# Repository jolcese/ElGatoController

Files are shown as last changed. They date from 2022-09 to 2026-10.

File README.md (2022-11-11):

# EL Gato Controller
  

  ## Description
  This is a standalone controller for the ElGato Lights. It's based on an ESP-WROOM-32 module but any ESP32 (or even ESP8266) should work with minimal changes.

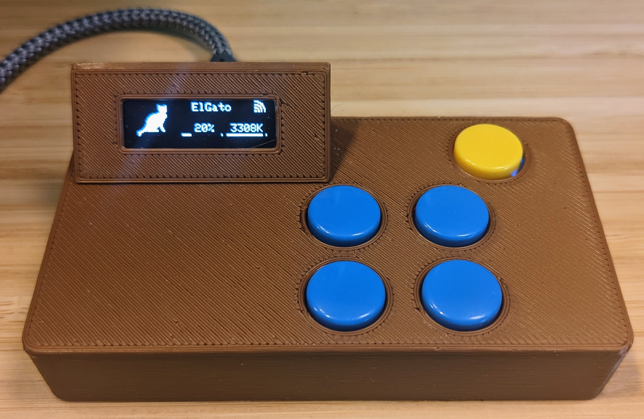
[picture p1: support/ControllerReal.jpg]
  <figure><figcaption>Controller with Display and 3D Printed Case</figcaption></figure>
  <br>
  <br>
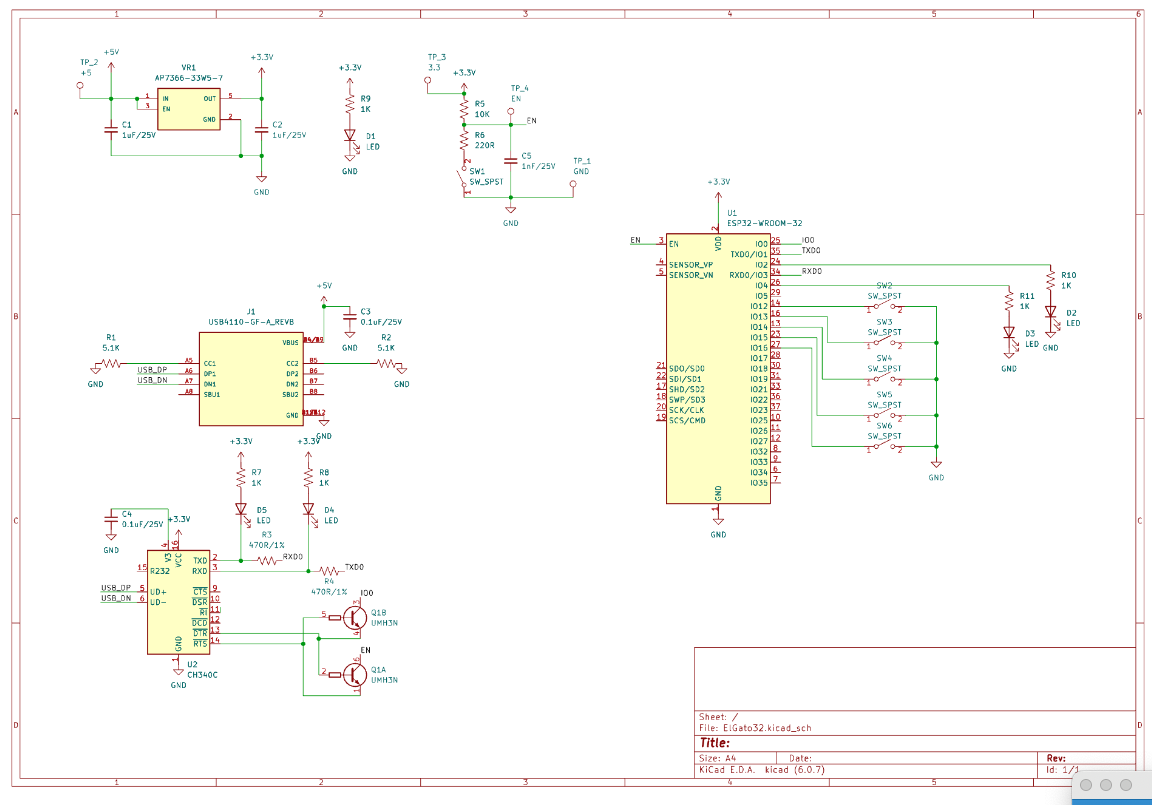
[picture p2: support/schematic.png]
  <figure><figcaption>Schematic for the module, USB-UART controller and buttons</figcaption></figure>
  <br>
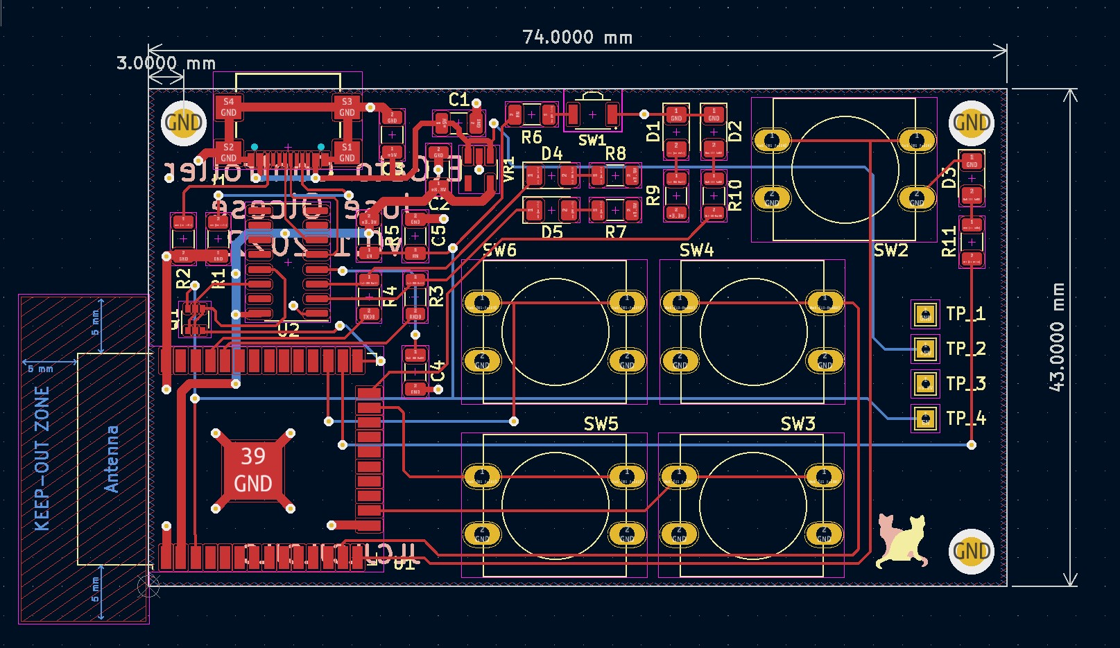
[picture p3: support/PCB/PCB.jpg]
  <figure><figcaption>Display has been added after designing the PCB so no header/connector</figcaption></figure>
  <br>

  ## Table of Contents
  * [ToDo](#todo)
  * [Installation](#installation)
  * [Usage](#usage)
  * [License](#license)
  * [Contributing](#contributing)
  * [Tests](#tests)
  * [Questions](#questions)

  ## ToDo
  
  - NTP
  - Dynamic lights config/ Web Server
  - Shortcut reboot
  - Brightness
  - Faster REST
  - FIx BAR size
  - ~Wifi Portal~
  - ~OLED Status~
  ## Installation
  Some of the tools used to build this project
  - [Plaftormio](https://platformio.org/)
  - [Kicad](https://www.kicad.org/)
  ## Usage
  Currently, the IPs for both lights are hardcoded. Until I made that discoverable thru Bonjour, numbers of lights and IPs will need to be manually mofified.
  
    main.cpp
    
    const String sLight1 = "192.168.30.137";
    const String sLight2 = "192.168.30.161";

  ## License
  This project is license under MIT

  ## Contributing
  Nothing

  ## Tests
  no tests

  ## Questions
  If you have any questions about this projects, please contact me directly at jolcese@gmail.com. You can view more of my projects at https://github.com/jolcese.

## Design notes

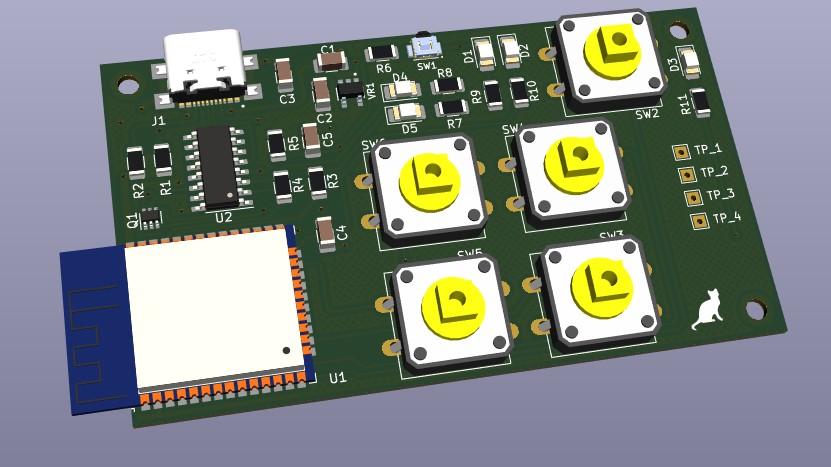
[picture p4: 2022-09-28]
support/3DModel-4.jpg

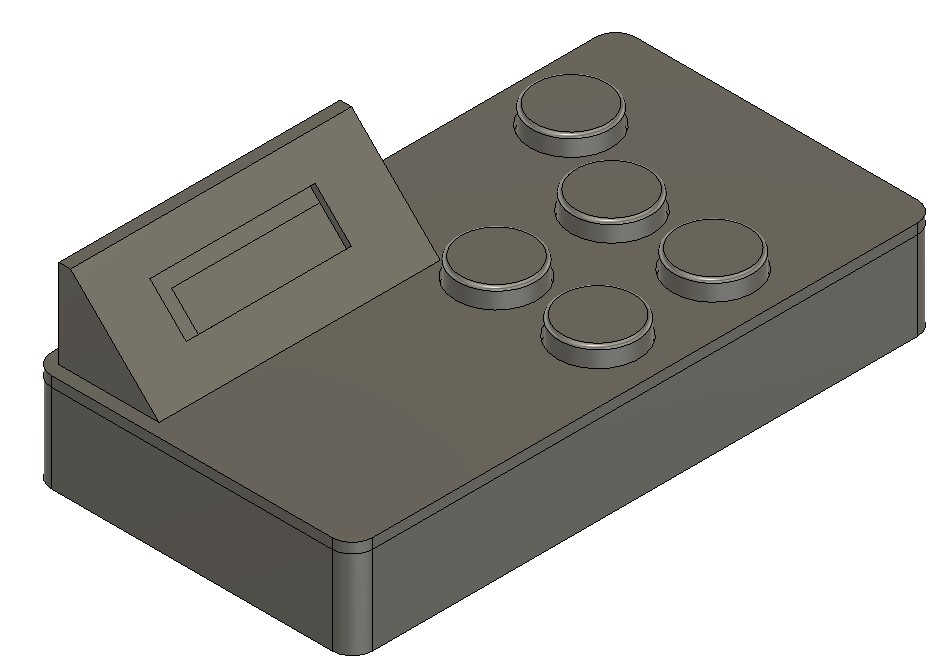
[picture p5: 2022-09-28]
support/3DModel-3.jpg

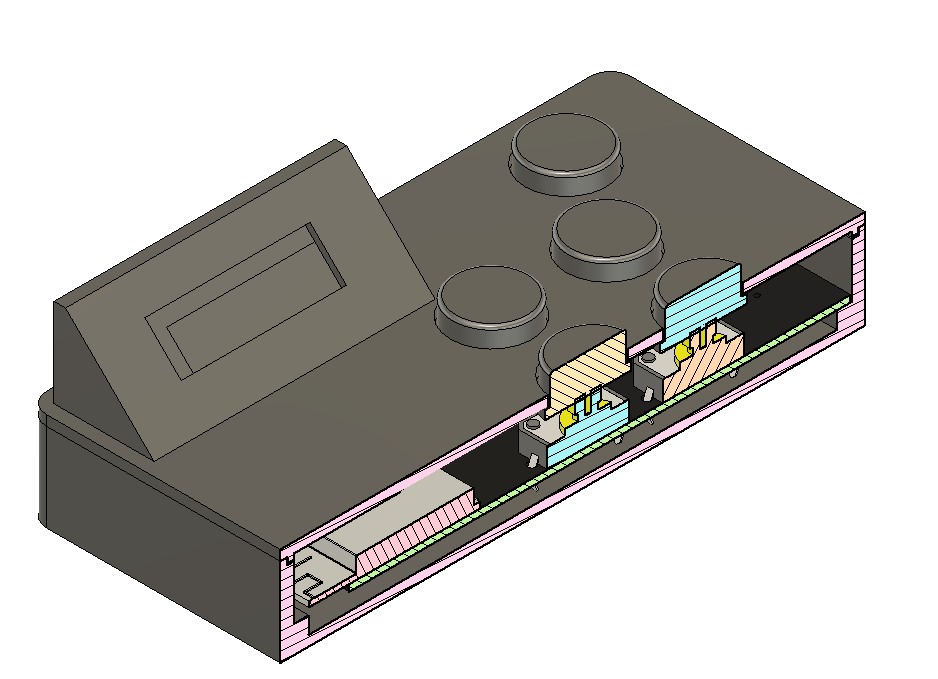
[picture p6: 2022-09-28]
support/3DModel-2.jpg

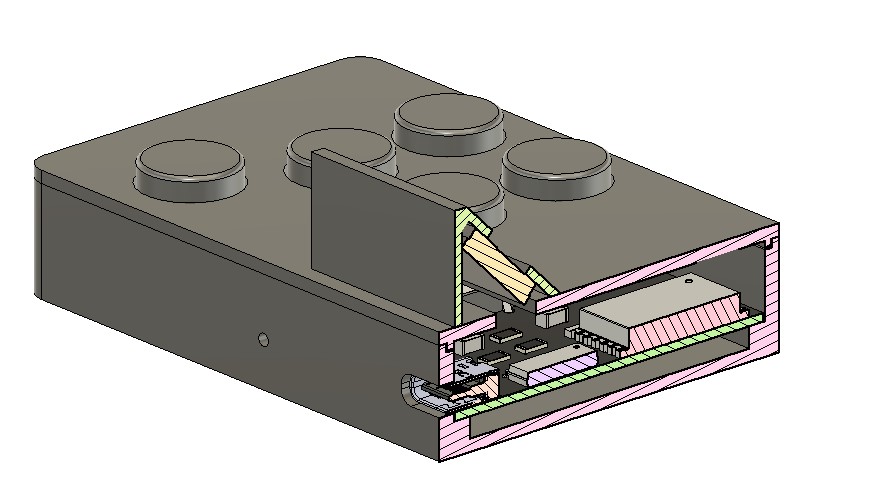
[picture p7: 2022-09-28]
support/3DModel-1.jpg

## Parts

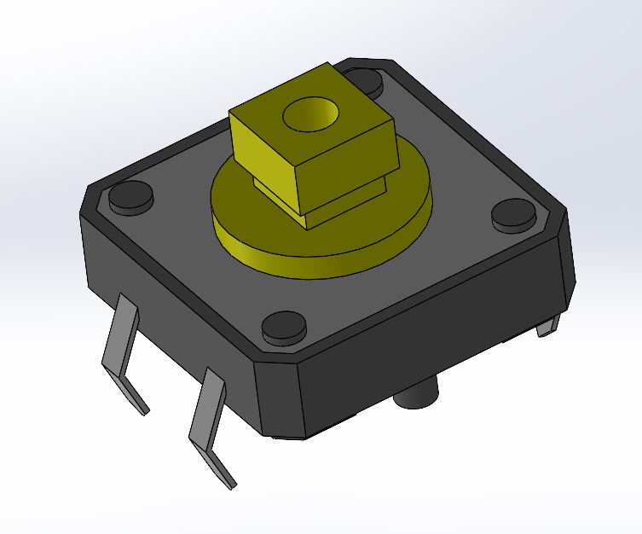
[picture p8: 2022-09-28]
kicad/ElGato32/Components/omron-b3f-12mm-tact-switch-1.snapshot.1/omron B3F/OMRON B3F 12mm TACT SWITCH..JPG

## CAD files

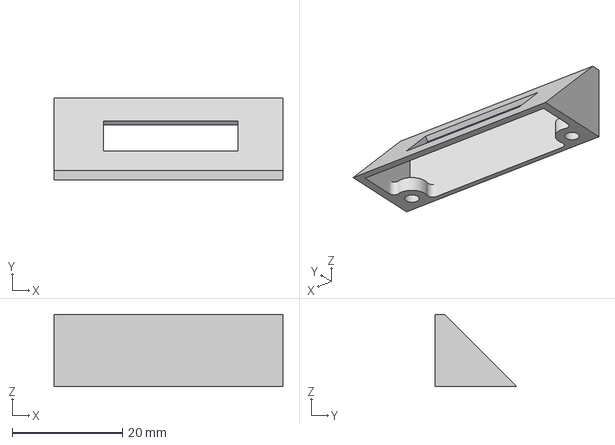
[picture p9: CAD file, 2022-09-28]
enclosure/Display.3mf
41.5 x 14.8 x 13.1 mm

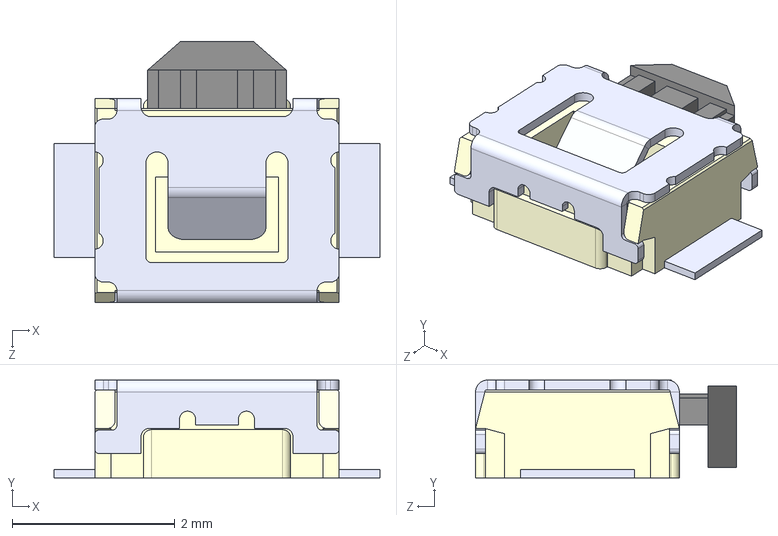
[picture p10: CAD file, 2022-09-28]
kicad/ElGato32/Components/B3U-3000P--3DModel-STEP-56544.STEP
4.00 x 1.20 x 3.20 mm

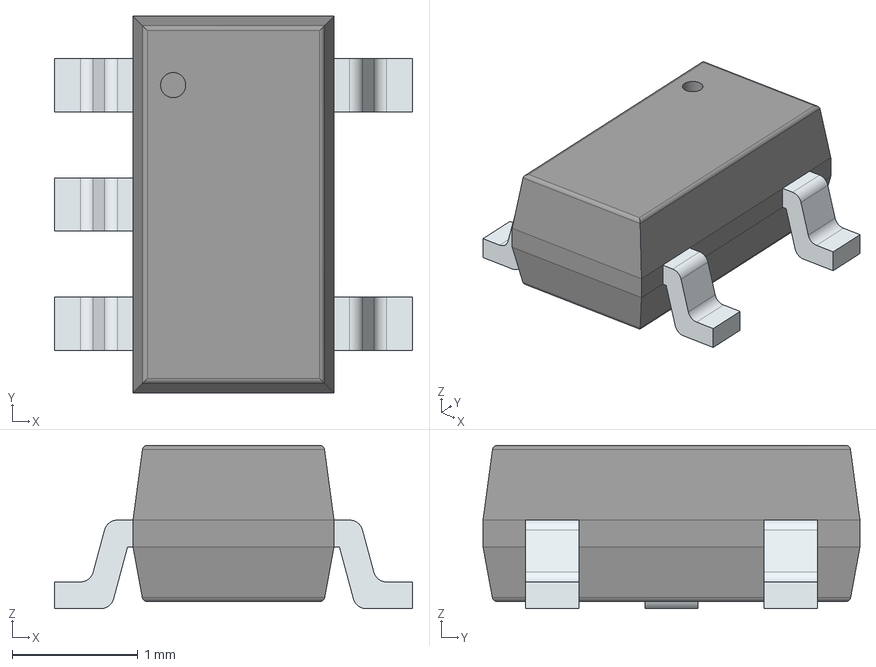
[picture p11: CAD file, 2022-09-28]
kicad/ElGato32/Components/LIB_AP7366-33W5-7/AP7366-33W5-7/3D/AP7366-33W5-7.stp
2.85 x 3.00 x 1.30 mm
PinsArrayL
PinsArrayR

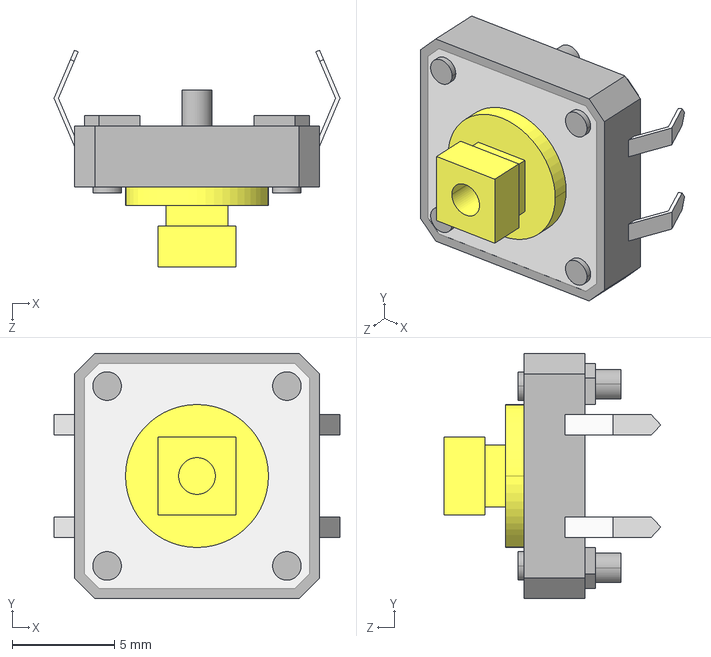
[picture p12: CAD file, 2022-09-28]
kicad/ElGato32/Components/omron-b3f-12mm-tact-switch-1.snapshot.1/omron B3F/OMRON B3F 12mm TACT SWITCH.STEP
14.0 x 12.0 x 10.6 mm

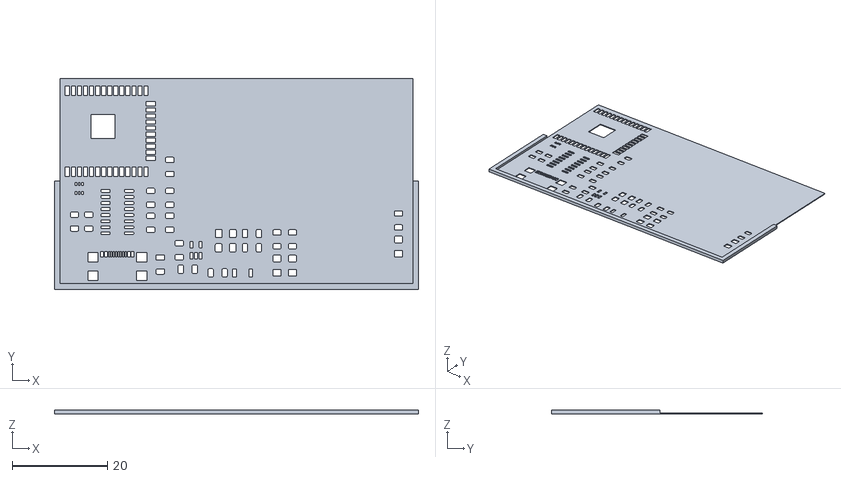
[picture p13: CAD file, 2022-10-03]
support/PCB/SolderPasteStencil-gts-8576637044.stl
76.4 x 44.2 x 0.8

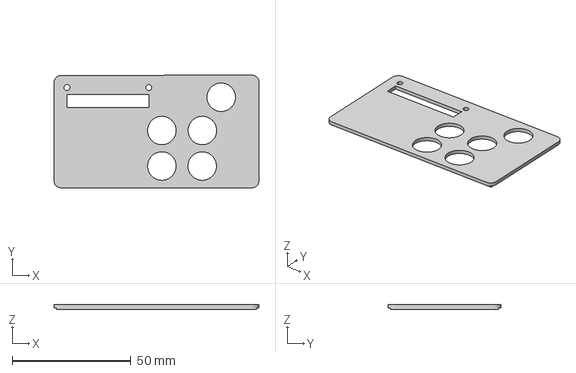
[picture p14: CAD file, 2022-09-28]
enclosure/Lid.3mf
86.4 x 47.5 x 2.30 mm

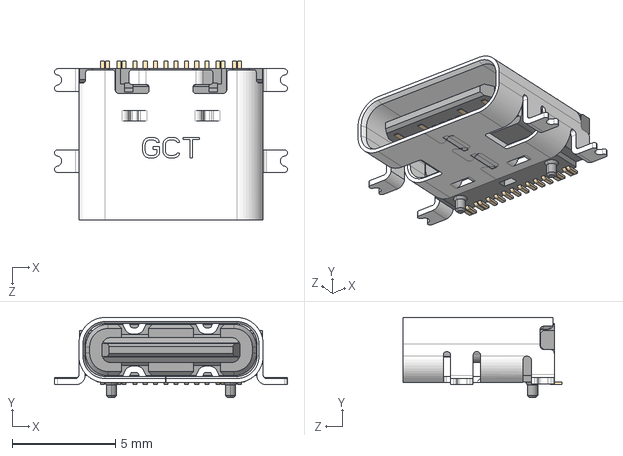
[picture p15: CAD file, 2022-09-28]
kicad/ElGato32/Components/USB4110-GF-A--3DModel-STEP-269445.STEP
11.3 x 3.89 x 7.70 mm

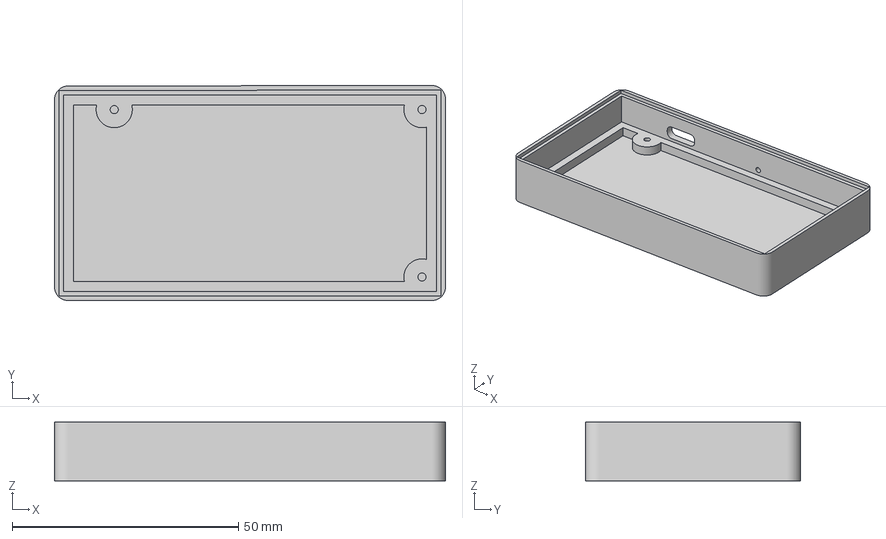
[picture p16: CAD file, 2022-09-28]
enclosure/Base.3mf
86.4 x 47.5 x 13.0 mm

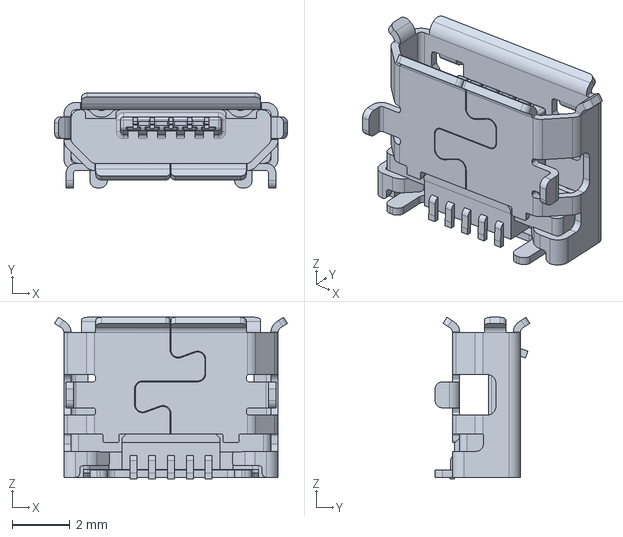
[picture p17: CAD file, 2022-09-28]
kicad/ElGato32/Components/10118194-0001LF/10118194-0001LF.step
8.05 x 3.27 x 5.58 mm

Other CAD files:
kicad/ElGato32/Components/LIB_AP7366-33W5-7/AP7366-33W5-7/Allegro/sot95p285x130-5n.psm
kicad/ElGato32/Components/LIB_AP7366-33W5-7/AP7366-33W5-7/DEHDL/ap7366_33w5_7/chips/chips.prt
kicad/ElGato32/Components/_Wemos.8a6fa8fd-bdae-4608-9551-e9ac450bc9c8.f3d

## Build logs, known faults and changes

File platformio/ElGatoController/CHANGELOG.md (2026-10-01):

# Changelog

All notable changes to the ElGato Controller firmware are documented here.

The format is based on [Keep a Changelog](https://keepachangelog.com/en/1.1.0/),
and this project adheres to [Semantic Versioning](https://semver.org/spec/v2.0.0.html).

The firmware version lives in [`include/version.h`](include/version.h) and is
printed over serial at startup, together with the git commit it was built from.

## [Unreleased]

## [0.6.0] - 2026-10-01

### Changed
- Button presses now update the on-screen state (brightness/temperature/on-off)
  immediately for instant visual feedback, instead of only after the network
  request. The light PUT follows a moment later, batched. Makes rapid repeated
  clicks feel responsive. `actionLight()` now just sends the current state.
- While no lights are known, discovery retries every 30s instead of waiting the
  full 5-minute poll interval, so a transient discovery miss at startup recovers
  quickly.

## [0.5.0] - 2026-10-01

### Changed
- Much faster button-to-light response: the action batching window dropped from
  600 ms to 150 ms, the blocking GET that ran before every action was removed
  (deltas apply to locally tracked state instead), and Nagle buffering is
  disabled on the PUT so the request goes out immediately.

## [0.4.0] - 2026-10-01

### Added
- Periodic mDNS re-discovery (every 30 min) plus automatic re-discovery when a
  known light stops answering, so a light that changed IP (DHCP) self-heals
  without needing to restart the controller or the light.
- Lights connectivity indicator on the display (top-left): a filled dot when the
  lights are reachable, a hollow circle with a slash when they are not.

### Fixed
- Color temperature bar moved opposite to the Kelvin number; the bar now tracks
  the displayed K value (low K = short bar).
- Disabled WiFi modem power save, which was dropping multicast packets and making
  mDNS discovery intermittently find only some (or none) of the lights.

## [0.3.0] - 2026-10-01

### Added
- OLED anti burn-in power management: the display dims after 15s idle and fully
  blanks after 60s idle, waking instantly on any button press. The GDDRAM buffer
  keeps refreshing while blanked, so content is current the moment it wakes.

### Changed
- mDNS discovery now runs multiple query passes and merges unique light IPs,
  instead of trusting a single query. Fixes only some lights being found when
  one doesn't answer the first query.

### Fixed
- Color temperature up/down buttons were inverted; swapped SW4/SW6 so each
  button changes temperature in the expected direction.

## [0.2.0] - 2026-10-01

### Added
- Automatic discovery of Elgato Key Lights over mDNS (`_elg._tcp`), replacing
  the two hardcoded IP addresses. Up to `MAX_LIGHTS` lights are now controlled.
- Firmware version tracking: `FW_VERSION` plus the git commit hash are compiled
  into the firmware and printed on the serial console at boot.

### Changed
- `getLightState()` reads from the first discovered light; `actionLight()` pushes
  updates to every discovered light.
- mDNS discovery retries a few times, since the first query after connecting
  often misses responses.

## [0.1.0] - initial

### Added
- WiFi provisioning via WiFiManager, OLED display, physical buttons for on/off,
  brightness and color temperature, controlling two Elgato lights at hardcoded
  IP addresses.

[Unreleased]: https://github.com/
[0.2.0]: https://github.com/
[0.1.0]: https://github.com/

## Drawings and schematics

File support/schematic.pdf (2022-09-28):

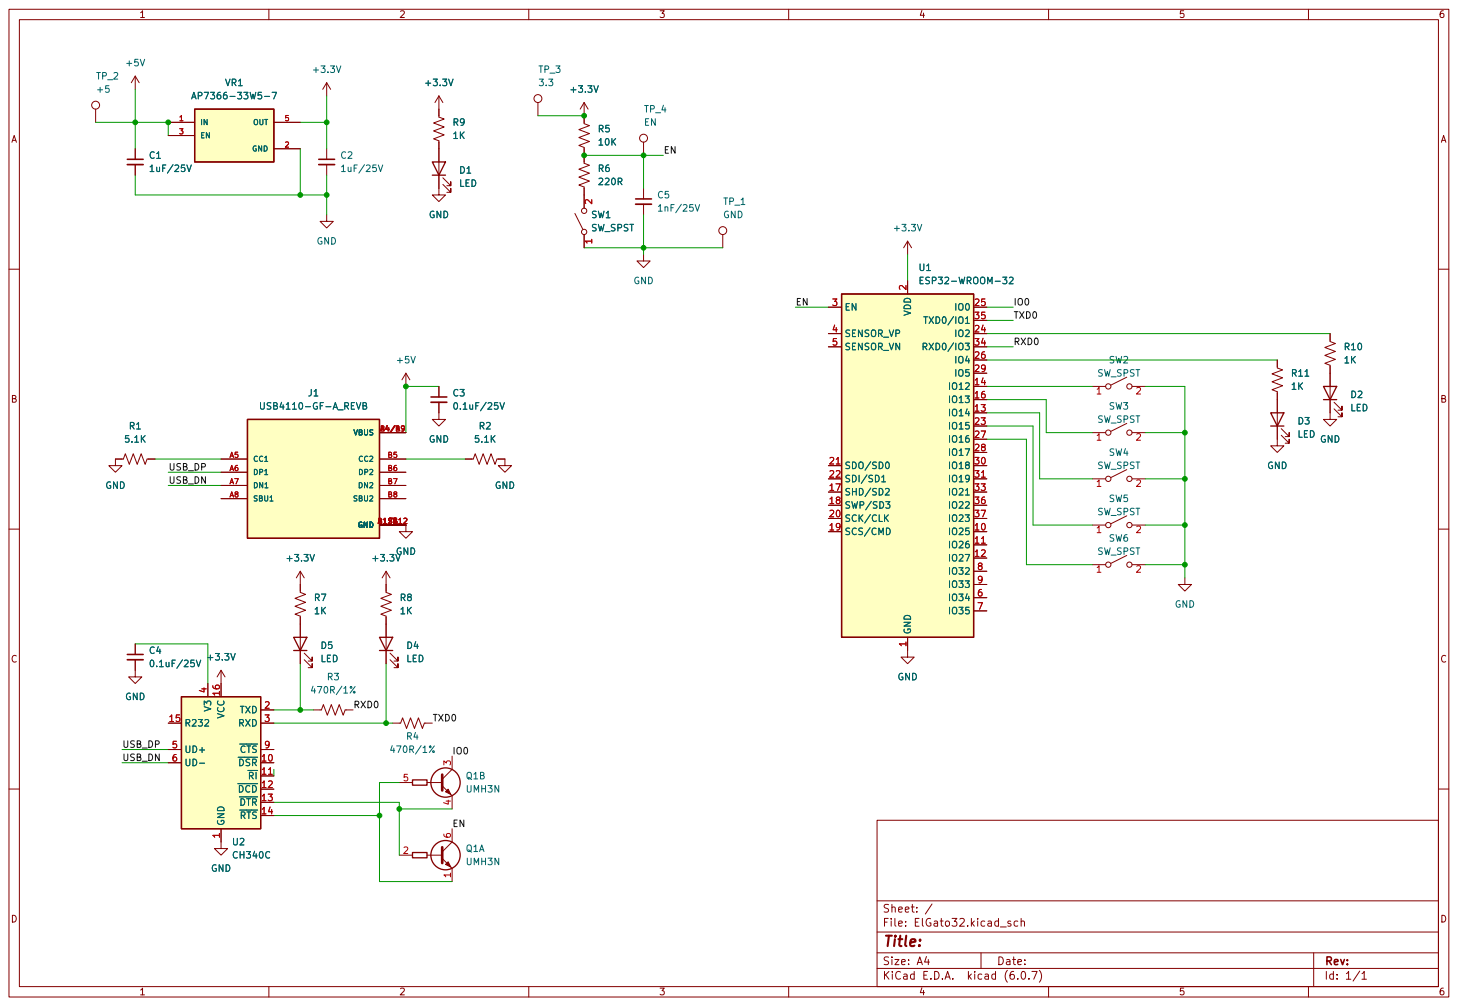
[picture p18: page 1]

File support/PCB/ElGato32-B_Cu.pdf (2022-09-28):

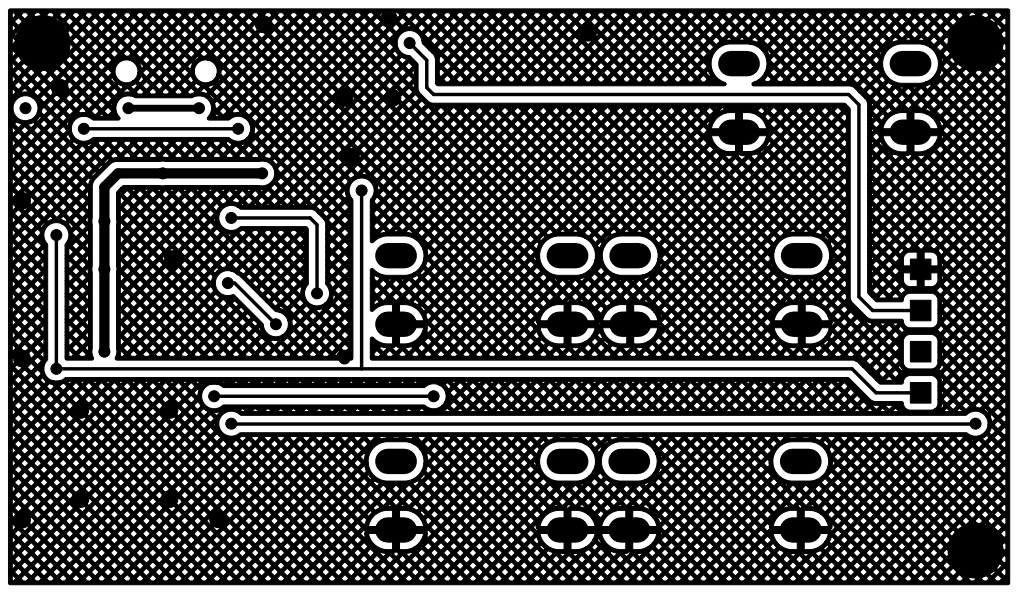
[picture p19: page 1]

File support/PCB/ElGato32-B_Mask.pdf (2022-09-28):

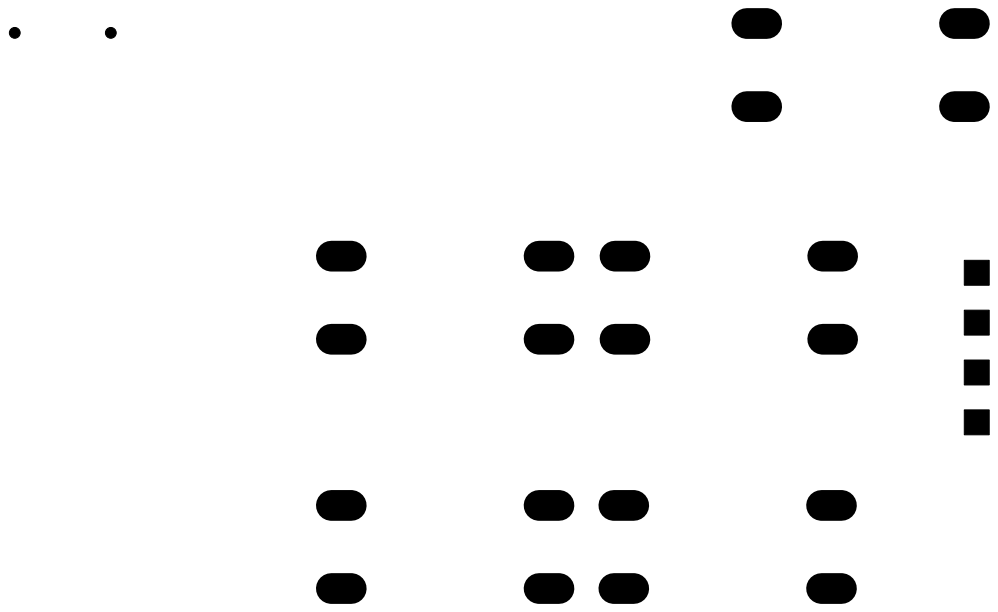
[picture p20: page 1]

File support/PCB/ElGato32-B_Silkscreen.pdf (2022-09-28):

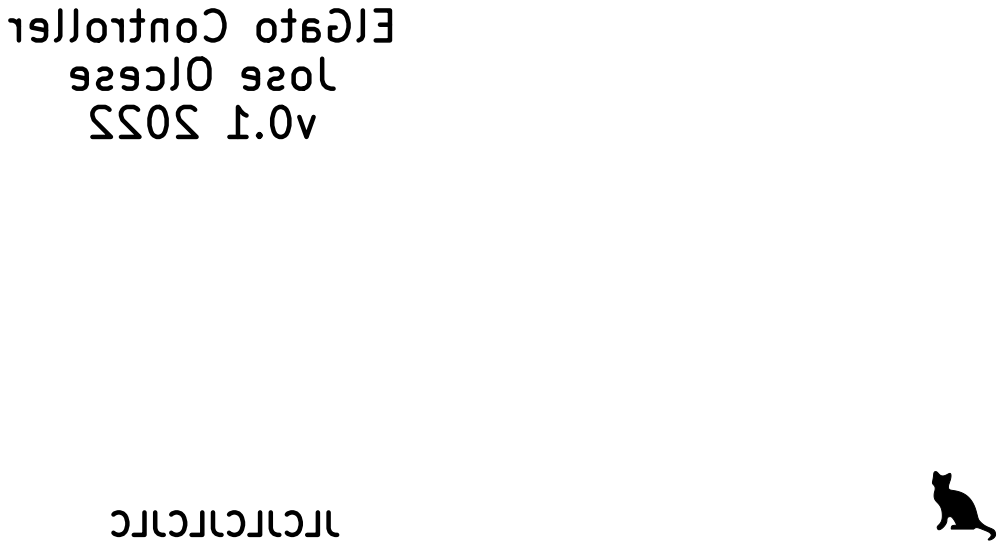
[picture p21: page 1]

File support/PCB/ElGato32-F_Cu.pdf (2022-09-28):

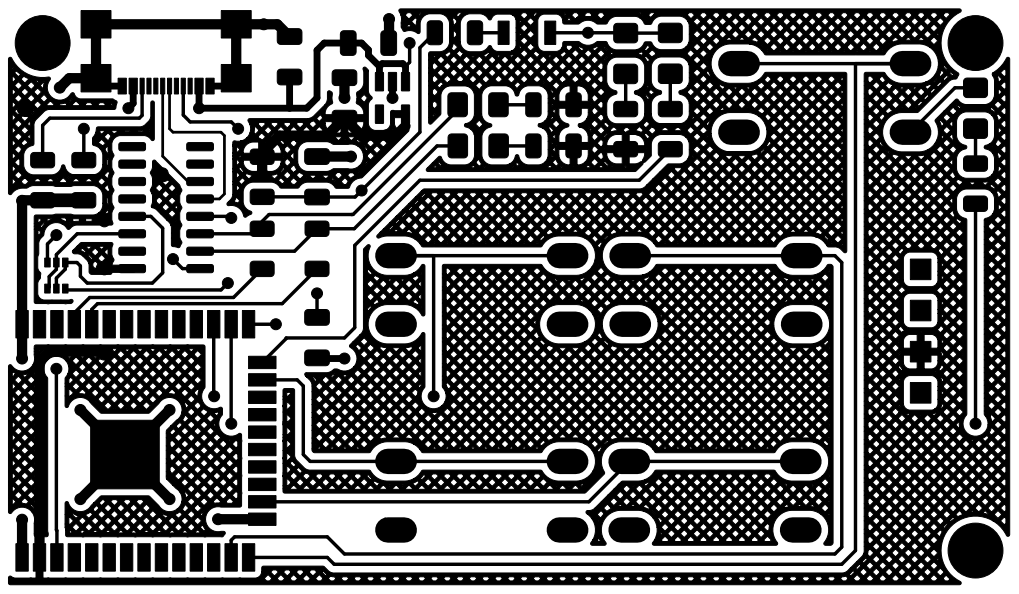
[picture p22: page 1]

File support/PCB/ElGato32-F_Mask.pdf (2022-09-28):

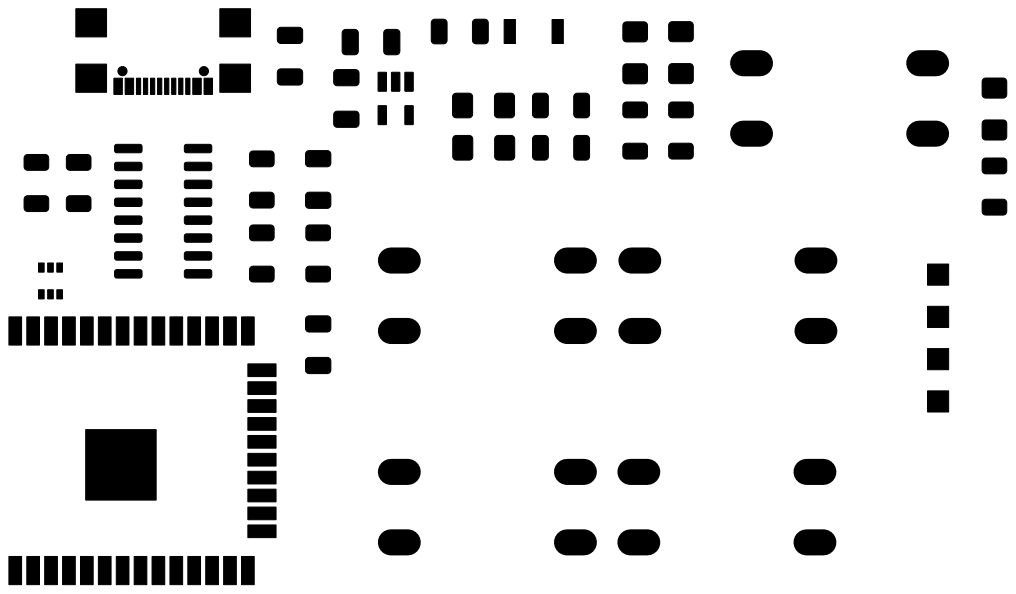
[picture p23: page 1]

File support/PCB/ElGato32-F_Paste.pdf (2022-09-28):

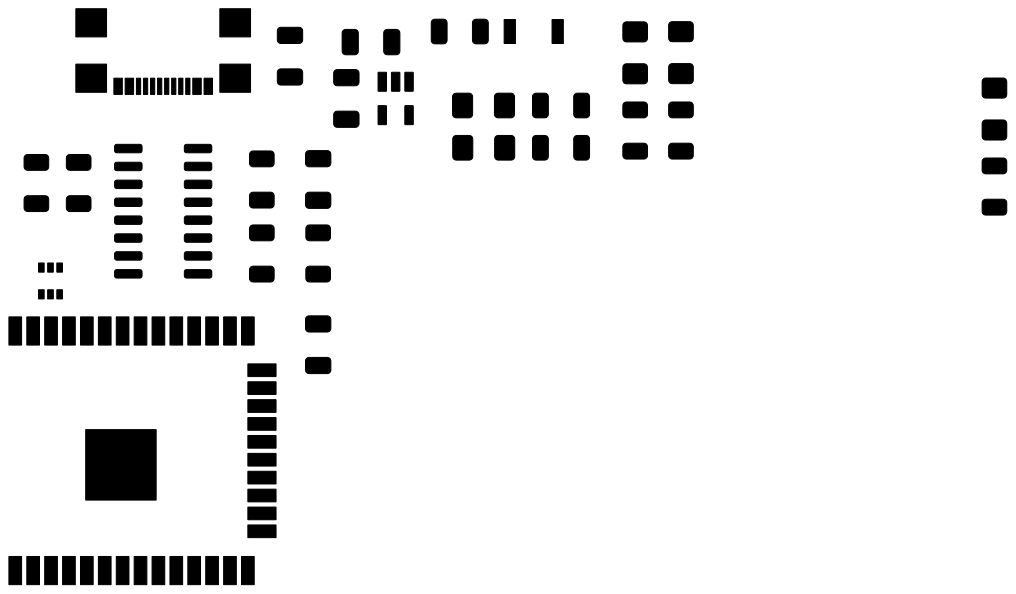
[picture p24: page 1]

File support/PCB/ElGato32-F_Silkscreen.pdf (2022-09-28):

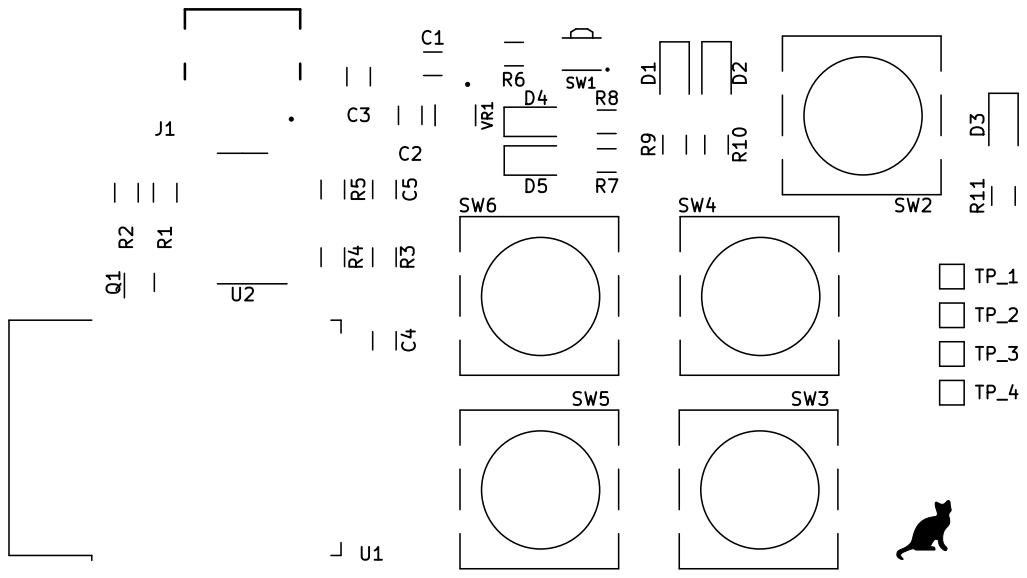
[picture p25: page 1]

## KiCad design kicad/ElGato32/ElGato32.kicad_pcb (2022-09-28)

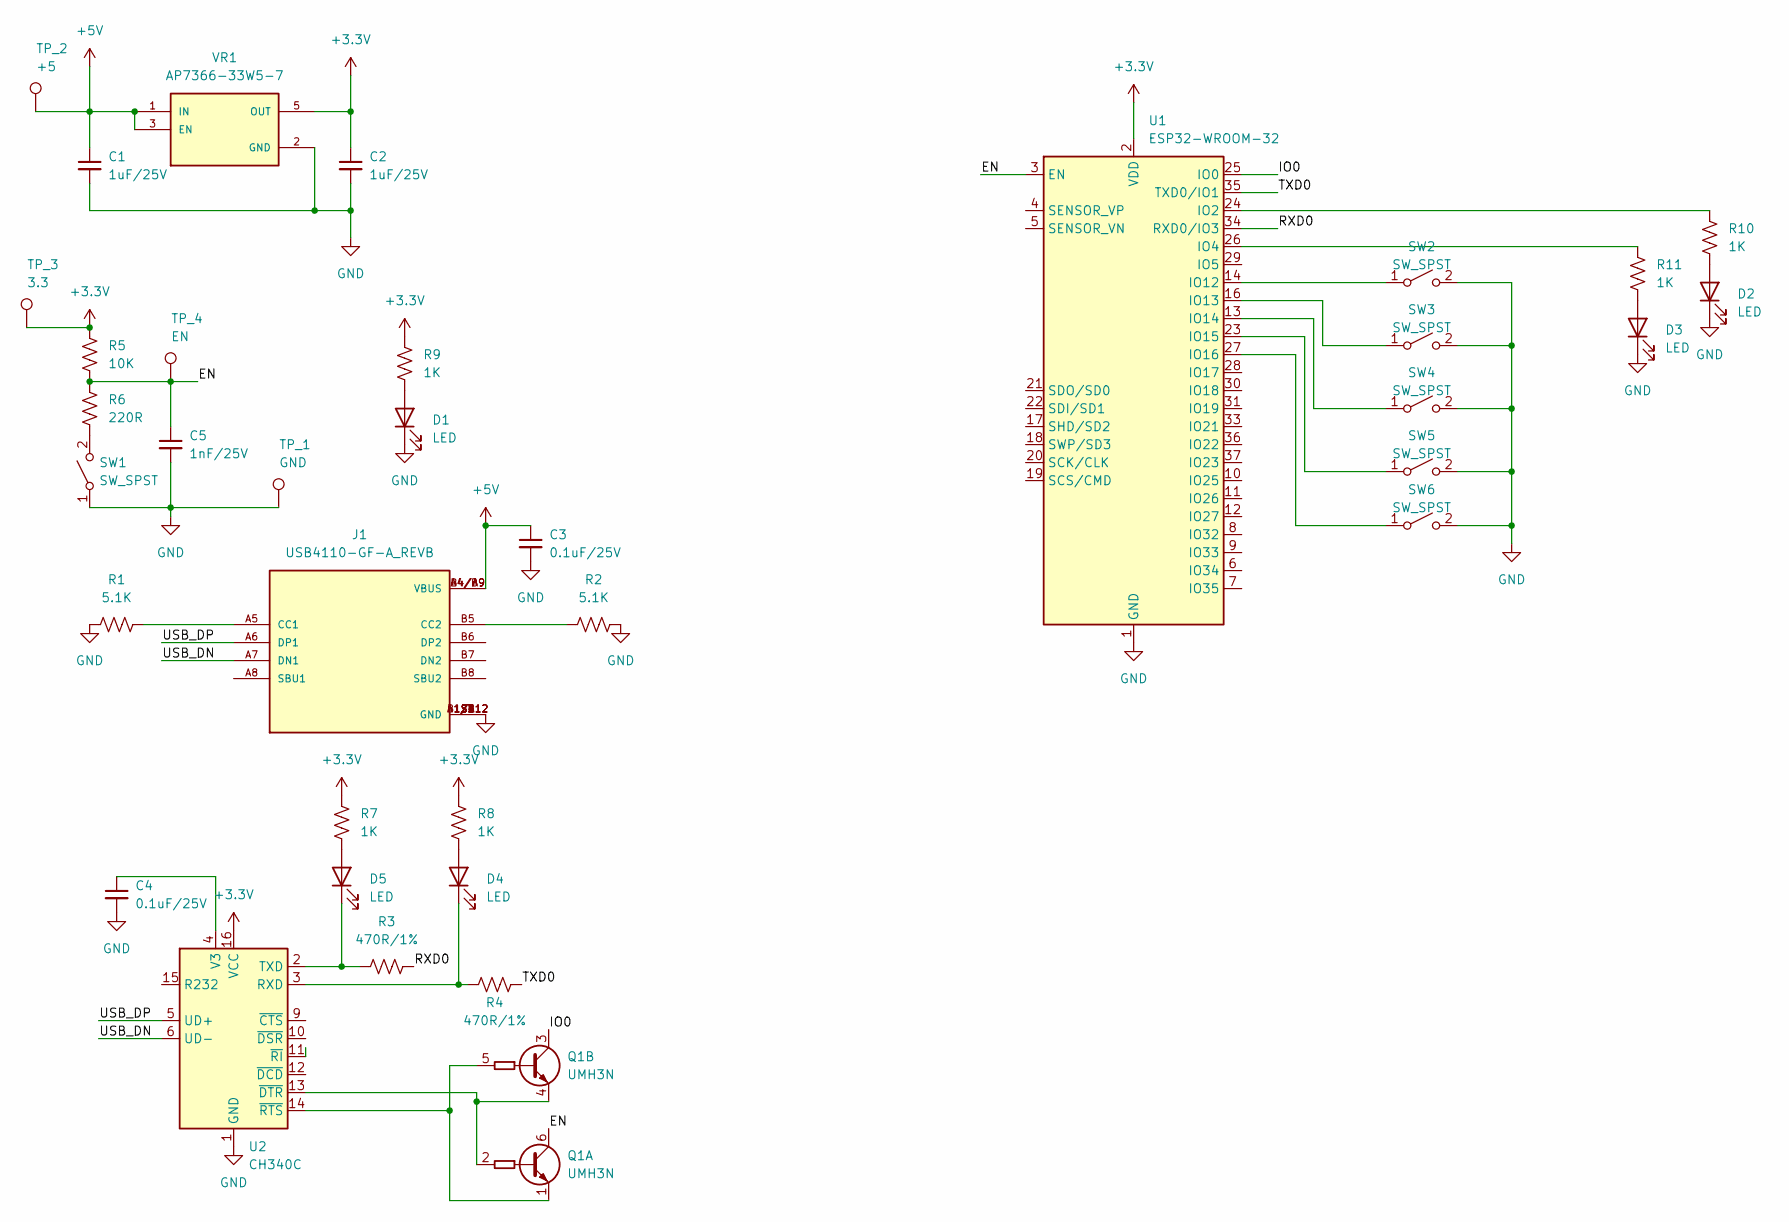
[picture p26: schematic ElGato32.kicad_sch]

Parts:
C1, C2: 1uF/25V; C_1206_3216Metric
C3, C4: 0.1uF/25V; C_1206_3216Metric
C5: 1nF/25V; C_1206_3216Metric
D1, D2, D3, D4, D5: LED; LED_1206_3216Metric_Pad1.42x1.75mm_HandSolder
J1: USB4110-GF-A_REVB; GCT_USB4110-GF-A_REVB; PARTREV B
Q1: UMH3N; SOT-363_SC-70-6
R1, R2: 5.1K; R_1206_3216Metric
R3, R4: 470R/1%; R_1206_3216Metric
R5: 10K; R_1206_3216Metric
R6: 220R; R_1206_3216Metric
R7, R8, R9, R10, R11: 1K; R_1206_3216Metric
SW1: SW_SPST; SW_B3U-3000P
SW2, SW3, SW4, SW5, SW6: SW_SPST; SW_PUSH-12mm
TP_1: GND; TestPoint_THTPad_1.5x1.5mm_Drill0.7mm
TP_2: +5; TestPoint_THTPad_1.5x1.5mm_Drill0.7mm
TP_3: 3.3; TestPoint_THTPad_1.5x1.5mm_Drill0.7mm
TP_4: EN; TestPoint_THTPad_1.5x1.5mm_Drill0.7mm
U1: ESP32-WROOM-32
U2: CH340C; SOIC-16_3.9x9.9mm_P1.27mm
VR1: AP7366-33W5-7; SOT95P285X140-5N; PARTREV 1-2

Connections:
+3.3V: C2.1, R5.2, R7.2, R8.2, R9.2, TP_3.1, U1.2 (VDD), U2.16 (VCC), VR1.5 (OUT)
+5V: C1.1, C3.1, J1.A4/B9 (VBUS), J1.B4/A9 (VBUS), TP_2.1, VR1.1 (IN), VR1.3 (EN)
/EN: C5.1, Q1.6 (C1), R5.1, R6.2, TP_4.1, U1.3 (EN)
/IO0: Q1.3 (C2), U1.25 (IO0)
/RXD0: R3.2, U1.34 (RXD0/IO3)
/TXD0: R4.2, U1.35 (TXD0/IO1)
/USB_DN: J1.A7 (DN1), U2.6 (UD-)
/USB_DP: J1.A6 (DP1), U2.5 (UD+)
GND: C1.2, C2.2, C3.2, C4.2, C5.2, D1.1 (K), D2.1 (K), D3.1 (K), J1.A1/B12 (GND), J1.B1/A12 (GND), J1.S1 (GND), J1.S2 (GND), J1.S3 (GND), J1.S4 (GND), R1.1, R2.2, SW1.1 (A), SW2.2 (B), SW3.2 (B), SW4.2 (B), SW5.2 (B), SW6.2 (B), TP_1.1, U1.1 (GND), U1.15 (GND), U1.38 (GND), U1.39 (GND), U2.1 (GND), VR1.2 (GND)
unnamed: D1.2 (A), R9.1
unnamed: D2.2 (A), R10.1
unnamed: D3.2 (A), R11.1
unnamed: D4.2 (A), R8.1
unnamed: D5.2 (A), R7.1
unnamed: Q1.1 (E1), Q1.5 (B2), U2.14 (~RTS)
unnamed: Q1.2 (B1), Q1.4 (E2), U2.13 (~DTR)
unnamed: J1.A5 (CC1), R1.2
unnamed: J1.B5 (CC2), R2.1
unnamed: D4.1 (K), R4.1, U2.3 (RXD)
unnamed: R6.1, SW1.2 (B)
unnamed: SW4.1 (A), U1.13 (IO14)
unnamed: SW2.1 (A), U1.14 (IO12)
unnamed: SW3.1 (A), U1.16 (IO13)
unnamed: SW5.1 (A), U1.23 (IO15)
unnamed: R10.2, U1.24 (IO2)
unnamed: R11.2, U1.26 (IO4)
unnamed: SW6.1 (A), U1.27 (IO16)
unnamed: D5.1 (K), R3.1, U2.2 (TXD)
unnamed: C4.1, U2.4 (V3)

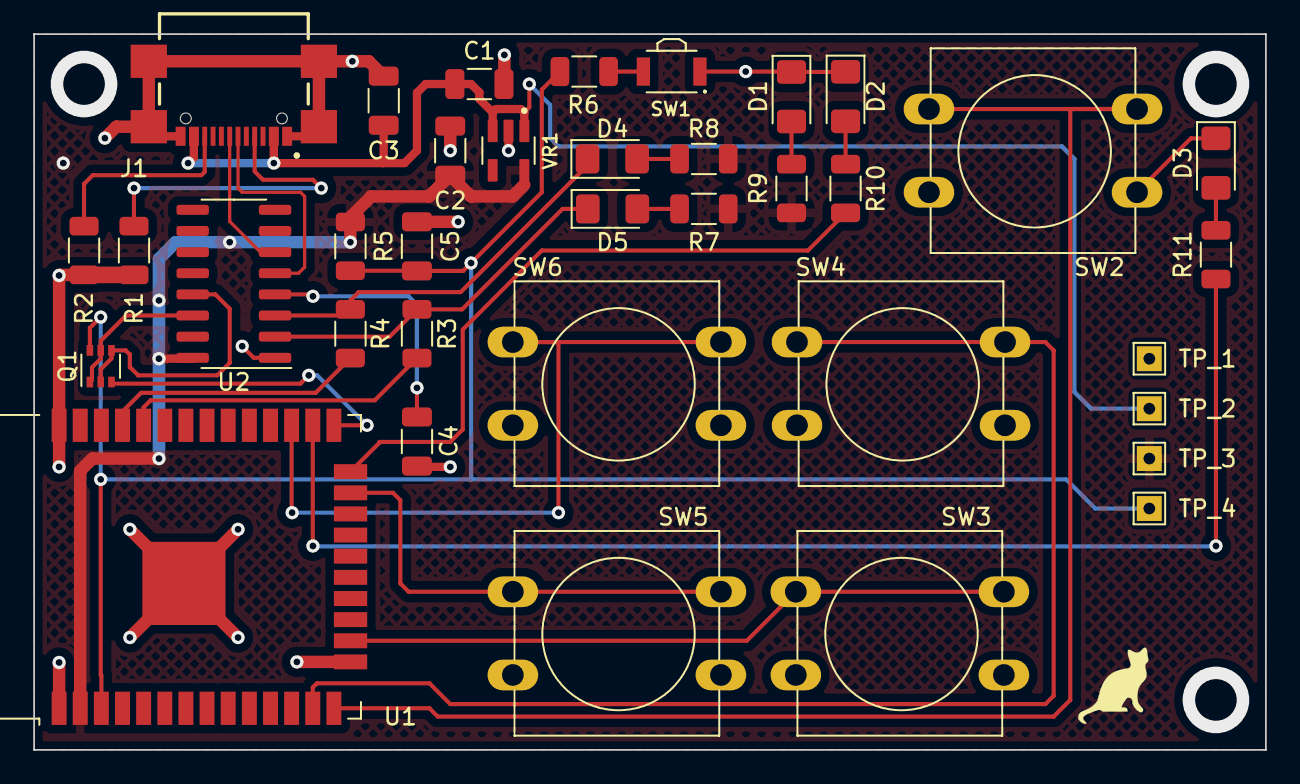
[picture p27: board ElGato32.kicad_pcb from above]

Board: 2 copper layers, 74.0 x 43.0 mm, 36 parts (0 on the bottom side), 29 nets.

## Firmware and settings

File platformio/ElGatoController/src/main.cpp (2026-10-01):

/*
 *  ElGato Controller
 *
*/
 
#include <Arduino.h>

#include <WiFi.h>
#include <HTTPClient.h>
#include <ESPmDNS.h>

#include <WiFiManager.h>          //https://github.com/tzapu/WiFiManager WiFi Configuration Magic
WiFiManager gWifiManager;

char gHostName[64];
boolean gFirstBoot = true;
#define WL_MAC_ADDR_LENGTH 6

// #include <WebServer.h>
// WebServer gWebServer(80);

#include <Arduino_JSON.h>

#include "display.h"
#include "logos.h"
#include "version.h"

// Elgato lights discovered via mDNS (_elg._tcp)
#define MAX_LIGHTS 8
String gLights[MAX_LIGHTS];
int gLightCount = 0;
bool gMdnsStarted = false;
bool gLightsOnline = false;                             // last poll reached a light?

// Re-discover at least this often so stale DHCP IPs self-heal without a reboot
#define DISCOVER_INTERVAL 1800000UL                     // 30 minutes
unsigned long lastDiscoverMillis = 0;

// Hardware Pins
const int ledWifiPin = 4;                       // D3
const int ledOnOffPin = 2;                      // D2

const int buttonOnOffPin = 12;                  // SW2
const int buttonIncreaseBrightnessPin = 13;     // SW3
const int buttonDecreaseBrightnessPin = 15;     // SW5      
const int buttonIncreaseTemperaturePin = 16;    // SW6 (swapped: temp buttons were inverted)
const int buttonDecreaseTemperaturePin = 14;    // SW4 (swapped: temp buttons were inverted)

// Buttons states
int onOffState = HIGH;                          // the current reading from the input pin
int lastOnOffState = LOW;                       // the previous reading from the input pin

int increaseBrightnessState = HIGH;             // the current reading from the input pin
int lastIncreaseBrightnessState = LOW;          // the previous reading from the input pin
int decreaseBrightnessState = HIGH;             // the current reading from the input pin
int lastDecreaseBrightnessState = LOW;          // the previous reading from the input pin

int increaseTemperatureState = HIGH;            // the current reading from the input pin
int lastIncreaseTemperatureState = LOW;         // the previous reading from the input pin
int decreaseTemperatureState = HIGH;            // the current reading from the input pin
int lastDecreaseTemperatureState = LOW;         // the previous reading from the input pin

// Debounce timers
unsigned long lastOnOffDebounceTime = 0;                // the last time the output pin was toggled
unsigned long lastIncreaseBrightnessDebounceTime = 0;   // the last time the output pin was toggled
unsigned long lastDecreaseBrightnessDebounceTime = 0;   // the last time the output pin was toggled
unsigned long lastIncreaseTemperatureDebounceTime = 0;  // the last time the output pin was toggled
unsigned long lastDecreaseTemperatureDebounceTime = 0;  // the last time the output pin was toggled
unsigned long debounceDelay = 50;                       // the debounce time; increase if the output flickers

unsigned long previousPollMillis = 0;                   // the last time poll was done
unsigned long pollDelay = 300000;

unsigned long previousActionMillis = 0;                 // the last time Action was sent
unsigned long actionDelay = 150;                        // batch rapid taps, but stay responsive

bool action = false;

// Display power management (anti burn-in): dim then blank the OLED when idle,
// wake instantly on any button press. The controller sits idle most of the day,
// so a mostly-static image lit 24/7 is what wears out the "always on" pixels.
#define DISPLAY_DIM_TIMEOUT 15000UL                     // dim after 15s idle
#define DISPLAY_OFF_TIMEOUT 60000UL                     // blank after 60s idle
unsigned long lastInteractionMillis = 0;                // last button press
bool gDisplayOn = true;
bool gDisplayDimmed = false;

#define BRIGHT_MIN 0
#define BRIGHT_MAX 100
#define BRIGHT_STEP 5

#define TEMP_MIN 143
#define TEMP_MAX 344
#define TEMP_STEP 20

// Initial Status
int onOffLightState = 0;                                // 0 - 1
int brightnessState = 0;                                // 0 - 100
int temperatureState = 344;                             // 143 - 344

void setupWifiManager() {

  uint8_t mac[WL_MAC_ADDR_LENGTH];
  WiFi.softAPmacAddress(mac);
  
  sprintf(gHostName, "ElGato-%02X%02X", mac[WL_MAC_ADDR_LENGTH - 2], mac[WL_MAC_ADDR_LENGTH - 1]);
  Serial.printf("Wifi Manager Setup - Name: %s\n", gHostName );
  
  // reset settings - wipe credentials for testing
  // gWifiManager.resetSettings();
  gWifiManager.setConfigPortalBlocking(false);

  //automatically connect using saved credentials if they exist
  //If connection fails it starts an access point with the specified name
  if(gWifiManager.autoConnect(gHostName)){
    Serial.println("Wi-Fi connected using saved credentials");
    gFirstBoot = false;
  }
  else {
    Serial.println("Wi-Fi manager portal running");
  }
}

void WiFiEvent(WiFiEvent_t event)
{
  Serial.printf("[WiFi-event] event: %d -- ", event);

  switch (event) {
    case ARDUINO_EVENT_WIFI_READY: 
      Serial.println("WiFi interface ready");
      break;
    case ARDUINO_EVENT_WIFI_SCAN_DONE:
      Serial.println("Completed scan for access points");
      break;
    case ARDUINO_EVENT_WIFI_STA_START:
      Serial.println("WiFi client started");
      break;
    case ARDUINO_EVENT_WIFI_STA_STOP:
      Serial.println("WiFi clients stopped");
      break;
    case ARDUINO_EVENT_WIFI_STA_CONNECTED:
      Serial.println("Connected to access point");
      break;
    case ARDUINO_EVENT_WIFI_STA_DISCONNECTED:
      Serial.println("Disconnected from WiFi access point");
      // previousWifiReconnectMillis = millis();
      break;
    case ARDUINO_EVENT_WIFI_STA_AUTHMODE_CHANGE:
      Serial.println("Authentication mode of access point has changed");
      break;
    case ARDUINO_EVENT_WIFI_STA_GOT_IP:
      Serial.print("Obtained IP address: ");
      Serial.println(WiFi.localIP());
      previousPollMillis = 0;
      break;
    case ARDUINO_EVENT_WIFI_STA_LOST_IP:
      Serial.println("Lost IP address and IP address is reset to 0");
      break;
    case ARDUINO_EVENT_WPS_ER_SUCCESS:
      Serial.println("WiFi Protected Setup (WPS): succeeded in enrollee mode");
      break;
    case ARDUINO_EVENT_WPS_ER_FAILED:
      Serial.println("WiFi Protected Setup (WPS): failed in enrollee mode");
      break;
    case ARDUINO_EVENT_WPS_ER_TIMEOUT:
      Serial.println("WiFi Protected Setup (WPS): timeout in enrollee mode");
      break;
    case ARDUINO_EVENT_WPS_ER_PIN:
      Serial.println("WiFi Protected Setup (WPS): pin code in enrollee mode");
      break;
    case ARDUINO_EVENT_WIFI_AP_START:
      Serial.println("WiFi access point started");
      break;
    case ARDUINO_EVENT_WIFI_AP_STOP:
      Serial.println("WiFi access point stopped");
      break;
    case ARDUINO_EVENT_WIFI_AP_STACONNECTED:
      Serial.println("Client connected");
      break;
    case ARDUINO_EVENT_WIFI_AP_STADISCONNECTED:
      Serial.println("Client disconnected");
      break;
    case ARDUINO_EVENT_WIFI_AP_STAIPASSIGNED:
      Serial.println("Assigned IP address to client");
      break;
    case ARDUINO_EVENT_WIFI_AP_PROBEREQRECVED:
      Serial.println("Received probe request");
      break;
    case ARDUINO_EVENT_WIFI_AP_GOT_IP6:
      Serial.println("AP IPv6 is preferred");
      break;
    case ARDUINO_EVENT_WIFI_STA_GOT_IP6:
      Serial.println("STA IPv6 is preferred");
      break;
    case ARDUINO_EVENT_ETH_GOT_IP6:
      Serial.println("Ethernet IPv6 is preferred");
      break;
    case ARDUINO_EVENT_ETH_START:
      Serial.println("Ethernet started");
      break;
    case ARDUINO_EVENT_ETH_STOP:
      Serial.println("Ethernet stopped");
      break;
    case ARDUINO_EVENT_ETH_CONNECTED:
      Serial.println("Ethernet connected");
      break;
    case ARDUINO_EVENT_ETH_DISCONNECTED:
      Serial.println("Ethernet disconnected");
      break;
    case ARDUINO_EVENT_ETH_GOT_IP:
      Serial.println("Obtained IP address");
      break;
    default: 
      break;
  }
}


// Turn the panel back to full brightness. The GDDRAM buffer keeps being
// refreshed by updateDisplay() even while blanked, so content is current.
void wakeDisplay() {
  if (!gDisplayOn) {
    display.ssd1306_command(SSD1306_DISPLAYON);
    gDisplayOn = true;
  }
  if (gDisplayDimmed) {
    display.dim(false);
    gDisplayDimmed = false;
  }
}

// Dim after a short idle, fully blank after a longer idle.
void manageDisplayPower(unsigned long now) {
  unsigned long idle = now - lastInteractionMillis;

  if (idle >= DISPLAY_OFF_TIMEOUT) {
    if (gDisplayOn) {
      display.ssd1306_command(SSD1306_DISPLAYOFF);
      gDisplayOn = false;
    }
  } else if (idle >= DISPLAY_DIM_TIMEOUT) {
    if (!gDisplayDimmed) {
      display.dim(true);
      gDisplayDimmed = true;
    }
  }
}

void updateDisplay() {

  display.clearDisplay();
  
  display.setTextColor(SSD1306_WHITE);
  display.setTextSize(1);
  display.setCursor(60,2);             // Start at top-left corner
  display.print("ElGato");

  display.setCursor(56,21);
  display.printf("%3d%%", brightnessState);

  long temp = 7000 - ((temperatureState - TEMP_MIN) * (7000-2900) / (TEMP_MAX - TEMP_MIN));
  display.setCursor(95,21);
  display.printf("%dK", temp);

  #define BAR_LEN 36  
  #define BAR_SPACE 5  

  int brightBar = (brightnessState * (BAR_LEN) / 100);
  display.drawLine(127 - BAR_LEN - BAR_SPACE, 30, 127 - BAR_LEN - BAR_SPACE, 31, SSD1306_WHITE);
  display.drawLine(127 - BAR_LEN - BAR_SPACE - BAR_LEN, 30, 127 - BAR_LEN - BAR_SPACE - BAR_LEN, 31, SSD1306_WHITE);
  display.drawLine(127 - BAR_LEN - BAR_SPACE - BAR_LEN, 30, 127 - BAR_LEN - BAR_SPACE - BAR_LEN + brightBar, 30, SSD1306_WHITE);
  display.drawLine(127 - BAR_LEN - BAR_SPACE - BAR_LEN, 31, 127 - BAR_LEN - BAR_SPACE - BAR_LEN + brightBar, 31, SSD1306_WHITE);

  // Kelvin is inverse to the raw Elgato value, so invert the bar to match the
  // displayed K number (low K -> short bar, high K -> long bar).
  int tempBar = BAR_LEN - ((temperatureState - TEMP_MIN) * (BAR_LEN) / (TEMP_MAX - TEMP_MIN));
  display.drawLine(127, 30, 127, 31, SSD1306_WHITE);
  display.drawLine(127 - BAR_LEN, 30, 127 - BAR_LEN , 31, SSD1306_WHITE);
  display.drawLine(127 - BAR_LEN, 30, 127 - BAR_LEN + tempBar, 30, SSD1306_WHITE);
  display.drawLine(127 - BAR_LEN, 31, 127 - BAR_LEN + tempBar, 31, SSD1306_WHITE);

  if (WiFi.status() == WL_CONNECTED) {
    display.drawBitmap(127 - WIFI_WIDTH, 0, wifi_logo, WIFI_WIDTH, WIFI_HEIGHT, SSD1306_WHITE);
    digitalWrite(ledWifiPin, HIGH);
  } else{
    digitalWrite(ledWifiPin, LOW);
  }

  if (onOffLightState == 0) {
    display.drawBitmap(10, 4, cat_off_logo, CAT_WIDTH, CAT_HEIGHT, SSD1306_WHITE);
    digitalWrite(ledOnOffPin, LOW);
  } else {
    display.drawBitmap(10, 4, cat_on_logo, CAT_WIDTH, CAT_HEIGHT, SSD1306_WHITE);
    digitalWrite(ledOnOffPin, HIGH);
  }

  // Lights connectivity indicator (top-left): filled dot = reachable,
  // hollow circle with a slash = unreachable (stale IP / light offline).
  if (gLightsOnline) {
    display.fillCircle(3, 4, 2, SSD1306_WHITE);
  } else {
    display.drawCircle(3, 4, 3, SSD1306_WHITE);
    display.drawLine(1, 6, 5, 2, SSD1306_WHITE);
  }

  display.display();
}


void setup()
{
  Serial.begin(115200);
  Serial.println();
  Serial.println();
  Serial.printf("ElGato Controller v%s (git %s, built %s %s)\n",
                FW_VERSION, GIT_REV, __DATE__, __TIME__);

  // Setup hardware oins
  pinMode(ledWifiPin, OUTPUT);
  digitalWrite(ledWifiPin, LOW);

  pinMode(ledOnOffPin, OUTPUT);
  digitalWrite(ledOnOffPin, LOW);

  pinMode(buttonOnOffPin, INPUT_PULLUP);
  pinMode(buttonIncreaseBrightnessPin, INPUT_PULLUP);
  pinMode(buttonDecreaseBrightnessPin, INPUT_PULLUP);
  pinMode(buttonIncreaseTemperaturePin, INPUT_PULLUP);
  pinMode(buttonDecreaseTemperaturePin, INPUT_PULLUP);

  // Setup Wifi
  WiFi.mode(WIFI_STA); // explicitly set mode, esp defaults to STA+AP
  // Disable modem power save: it drops multicast packets, which makes mDNS
  // discovery flaky and intermittent. This board is mains-powered, so the
  // extra radio-on current is a non-issue.
  WiFi.setSleep(false);
  WiFi.onEvent(WiFiEvent);

  // Reset Wifi setting if OnOff pressed for 5 seconds
  if (digitalRead(buttonOnOffPin) == LOW) {
    delay(5000);
    if (digitalRead(buttonOnOffPin) == LOW) {     
      gWifiManager.resetSettings();
      Serial.println("Wifi reset!");
    }
  }
  setupWifiManager();

  // gWebServer.begin();

  setupDisplay();
  lastInteractionMillis = millis();
  updateDisplay();
}

void discoverLights() {

  if (WiFi.status() != WL_CONNECTED) return;

  // mDNS responder must be running before we can query
  if (!gMdnsStarted) {
    if (MDNS.begin(gHostName)) {
      gMdnsStarted = true;
    } else {
      Serial.println("discoverLights - MDNS.begin() failed");
      return;
    }
  }

  // Elgato Key Lights advertise the service _elg._tcp. mDNS answers trickle in
  // across queries and not every light replies to the first one, so run a few
  // passes and merge unique IPs rather than trusting a single query.
  gLightCount = 0;
  for (int pass = 1; pass <= 3 && gLightCount < MAX_LIGHTS; pass++) {
    Serial.printf("discoverLights - querying _elg._tcp (pass %d/3) ...\n", pass);
    int n = MDNS.queryService("elg", "tcp");

    for (int i = 0; i < n && gLightCount < MAX_LIGHTS; i++) {
      String host = MDNS.hostname(i);
      IPAddress ip = MDNS.IP(i);

      // The A record sometimes lags the SRV/PTR answer, leaving IP as 0.0.0.0.
      // Resolve the hostname directly as a fallback.
      if (ip == IPAddress((uint32_t)0)) {
        ip = MDNS.queryHost(host.c_str());
      }
      if (ip == IPAddress((uint32_t)0)) {
        Serial.printf("discoverLights - skipping %s (could not resolve IP)\n", host.c_str());
        continue;
      }

      // Skip IPs we already recorded in an earlier pass.
      String ipStr = ip.toString();
      bool known = false;
      for (int j = 0; j < gLightCount; j++) {
        if (gLights[j] == ipStr) { known = true; break; }
      }
      if (known) continue;

      gLights[gLightCount] = ipStr;
      Serial.printf("discoverLights - found light %d: %s (%s:%d)\n",
                    gLightCount,
                    host.c_str(),
                    ipStr.c_str(),
                    MDNS.port(i));
      gLightCount++;
    }
  }
  Serial.printf("discoverLights - %d light(s) found\n", gLightCount);
}

// Returns true if the light responded; also updates gLightsOnline so the
// display can show whether the lights are reachable.
bool getLightState() {

  JSONVar myJSONPayload;

  if (gLightCount == 0) {
    Serial.println("getLightState - no lights discovered yet");
    gLightsOnline = false;
    return false;
  }

  WiFiClient client;
  HTTPClient httpClient;
  int httpReturnCode;

  // Get status from the first discovered light
  Serial.println("getLightState - GET: http://" + gLights[0] + ":9123/elgato/lights");
  httpClient.begin(client, "http://" + gLights[0] + ":9123/elgato/lights"); //HTTP
  httpClient.addHeader("Content-Type", "application/json");
  httpReturnCode = httpClient.GET();

  bool ok = false;
  if (httpReturnCode == HTTP_CODE_OK) {
    const String& payload = httpClient.getString();
    Serial.print("getLightState - Status: ");
    Serial.print(HTTP_CODE_OK);
    Serial.print(" - ");
    Serial.println(payload);
    myJSONPayload = JSON.parse(payload);

    onOffLightState = (int)myJSONPayload["lights"][0]["on"];
    brightnessState = (int)myJSONPayload["lights"][0]["brightness"];
    temperatureState = (int)myJSONPayload["lights"][0]["temperature"];

    ok = true;
  } else {
    Serial.printf("getLightState - GET... failed, error: %s\n", httpClient.errorToString(httpReturnCode).c_str());
  }
  httpClient.end();

  gLightsOnline = ok;
  return ok;
}

void setLightState(String ip, JSONVar payload) {

  int httpReturnCode;

  WiFiClient client;
  client.setNoDelay(true);  // send the small PUT immediately (no Nagle buffering)
  HTTPClient httpClient;

  Serial.print ("PUT: http://" + ip + ":9123/elgato/lights - ");
  Serial.println(JSON.stringify(payload));

  bool exitloop = false;
  int counter = 0;

  while (exitloop == false) {
    httpClient.begin(client, "http://" + ip + ":9123/elgato/lights");
    httpClient.addHeader("Content-Type", "application/json");
    httpReturnCode = httpClient.PUT(JSON.stringify(payload));

    // httpReturnCode will be negative on error
    if (httpReturnCode > 0) {
      if (httpReturnCode == HTTP_CODE_OK) {
        const String& payload = httpClient.getString();
        Serial.print("Status: ");
        Serial.println(HTTP_CODE_OK);

        exitloop = true;
      }
    } else {
      Serial.printf("[HTTP] PUT... failed, error: %s\n", httpClient.errorToString(httpReturnCode).c_str());
    }
    counter++;
    if (counter > 3) exitloop = true;
    
    httpClient.end();
  }
}
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
void loop()
{
  unsigned long localMillis = millis();

  // OnOff Button
  int onOffPress = evaluateButton(buttonOnOffPin,
                                  localMillis,
                                  & onOffState,
                                  & lastOnOffState,
                                  & lastOnOffDebounceTime,
                                  1);

  // IncreaseBrightness Button
  int increaseBrightnessPress = evaluateButton(buttonIncreaseBrightnessPin,
                                          localMillis,
                                          & increaseBrightnessState,
                                          & lastIncreaseBrightnessState,
                                          & lastIncreaseBrightnessDebounceTime,
                                          BRIGHT_STEP);

  // DecreaseBrightness Button
  int decreaseBrightnessPress = evaluateButton(buttonDecreaseBrightnessPin,
                                          localMillis,
                                          & decreaseBrightnessState,
                                          & lastDecreaseBrightnessState,
                                          & lastDecreaseBrightnessDebounceTime,
                                          BRIGHT_STEP);

  // IncreaseTemperature Button
  int increaseTemperaturePress = evaluateButton(buttonIncreaseTemperaturePin,
                                          localMillis,
                                          & increaseTemperatureState,
                                          & lastIncreaseTemperatureState,
                                          & lastIncreaseTemperatureDebounceTime,
                                          TEMP_STEP);

  // DecreaseTemperature Button
  int decreaseTemperaturePress = evaluateButton(buttonDecreaseTemperaturePin,
                                          localMillis,
                                          & decreaseTemperatureState,
                                          & lastDecreaseTemperatureState,
                                          & lastDecreaseTemperatureDebounceTime,
                                          TEMP_STEP);

  // Apply each press to the local state immediately so the display reacts
  // instantly; the actual light PUT is sent (batched) a moment later.
  if (onOffPress) {
    onOffLightState = (onOffLightState == 0) ? 1 : 0;
  }

  int brightnessDelta = increaseBrightnessPress - decreaseBrightnessPress;
  if (brightnessDelta != 0) {
    brightnessState += brightnessDelta;
    if (brightnessState < BRIGHT_MIN) brightnessState = BRIGHT_MIN;
    if (brightnessState > BRIGHT_MAX) brightnessState = BRIGHT_MAX;
  }

  int temperatureDelta = increaseTemperaturePress - decreaseTemperaturePress;
  if (temperatureDelta != 0) {
    temperatureState += temperatureDelta;
    if (temperatureState < TEMP_MIN) temperatureState = TEMP_MIN;
    if (temperatureState > TEMP_MAX) temperatureState = TEMP_MAX;
  }

  // Any button press wakes the display and resets the idle timer (anti burn-in)
  if (onOffPress || brightnessDelta != 0 || temperatureDelta != 0) {
    lastInteractionMillis = localMillis;
    wakeDisplay();
  }
  manageDisplayPower(localMillis);

  updateDisplay();

  // Do we need to send action? 
  if (((localMillis - previousActionMillis) > actionDelay && action == true) && WiFi.status() == WL_CONNECTED) {
    previousActionMillis = localMillis; 
    action = false;    
    
    Serial.println("loop - calling actionLight()...");
    actionLight();
  }

  // Polling light. While no lights are known (e.g. a transient discovery miss
  // at startup) retry quickly rather than waiting the full poll interval.
  unsigned long effectivePollDelay = (gLightCount == 0) ? 30000UL : pollDelay;
  if (((localMillis - previousPollMillis) > effectivePollDelay || previousPollMillis == 0 ) && WiFi.status() == WL_CONNECTED) {
    previousPollMillis = localMillis;

    // (Re)discover lights if we don't know any yet, or on a periodic interval
    // so a light that changed IP (DHCP) is picked up without a reboot.
    if (gLightCount == 0 || (localMillis - lastDiscoverMillis) > DISCOVER_INTERVAL) {
      discoverLights();
      lastDiscoverMillis = localMillis;
    }

    Serial.println("loop - calling getLightState()...");
    if (!getLightState() && gLightCount > 0) {
      // A known light stopped answering - most likely a stale IP. Force a
      // fresh discovery and retry once so it self-heals.
      Serial.println("loop - light unreachable, re-discovering...");
      discoverLights();
      lastDiscoverMillis = localMillis;
      getLightState();
    }
  }

  while (WiFi.status() != WL_CONNECTED && gFirstBoot == false )
  {
    Serial.println("Reconnect Wifi!");
    setupWifiManager();
  }

  gWifiManager.process();
  // gWebServer.handleClient();

  updateDisplay();
  
  delay(10);

}

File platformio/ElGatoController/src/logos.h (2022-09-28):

// 'cat', 26x28px
#define CAT_HEIGHT   28
#define CAT_WIDTH    26
static const unsigned char PROGMEM cat_on_logo[] = {
	0x00, 0x00, 0x10, 0x40, 0x00, 0x00, 0x1f, 0xc0, 0x00, 0x00, 0x1f, 0xc0, 0x00, 0x00, 0x1f, 0xc0, 
	0x00, 0x00, 0x1f, 0xc0, 0x00, 0x00, 0x0f, 0xc0, 0x00, 0x00, 0x0f, 0x80, 0x00, 0x00, 0x3f, 0x80, 
	0x00, 0x03, 0xff, 0xc0, 0x00, 0x0f, 0xff, 0xc0, 0x00, 0x1f, 0xff, 0xc0, 0x00, 0x3f, 0xff, 0x80, 
	0x00, 0x7f, 0xff, 0x00, 0x00, 0x7f, 0xff, 0x00, 0x00, 0xff, 0xfe, 0x00, 0x00, 0xff, 0xfe, 0x00, 
	0x00, 0xff, 0xfc, 0x00, 0x00, 0xff, 0xfc, 0x00, 0x01, 0xff, 0xfc, 0x00, 0x01, 0xff, 0xcc, 0x00, 
	0x03, 0xff, 0x8e, 0x00, 0x07, 0xff, 0x06, 0x00, 0x0f, 0xff, 0xc7, 0x00, 0x3e, 0xff, 0xc3, 0x00, 
	0xf0, 0x00, 0x00, 0x00, 0xc0, 0x00, 0x00, 0x00, 0xc0, 0x00, 0x00, 0x00, 0x80, 0x00, 0x00, 0x00
};

static const unsigned char PROGMEM cat_off_logo[] = {

	0x00, 0x00, 0x10, 0x40, 0x00, 0x00, 0x1f, 0xc0, 0x00, 0x00, 0x10, 0x40, 0x00, 0x00, 0x10, 0x40, 
	0x00, 0x00, 0x10, 0x40, 0x00, 0x00, 0x08, 0x40, 0x00, 0x00, 0x08, 0x80, 0x00, 0x00, 0x30, 0x80, 
	0x00, 0x03, 0xc0, 0x40, 0x00, 0x0c, 0x00, 0x40, 0x00, 0x10, 0x00, 0x40, 0x00, 0x20, 0x00, 0x80, 
	0x00, 0x40, 0x01, 0x00, 0x00, 0x40, 0x01, 0x00, 0x00, 0x80, 0x02, 0x00, 0x00, 0x80, 0x02, 0x00, 
	0x00, 0x80, 0x04, 0x00, 0x00, 0x80, 0x04, 0x00, 0x01, 0x00, 0x3c, 0x00, 0x01, 0x00, 0x4c, 0x00, 
	0x02, 0x00, 0x8e, 0x00, 0x04, 0x01, 0x06, 0x00, 0x0b, 0x00, 0xc7, 0x00, 0x3e, 0xff, 0xc3, 0x00, 
	0xf0, 0x00, 0x00, 0x00, 0xc0, 0x00, 0x00, 0x00, 0xc0, 0x00, 0x00, 0x00, 0x80, 0x00, 0x00, 0x00
};

// 'wifi', 10x10px
#define WIFI_HEIGHT   10
#define WIFI_WIDTH    10
static const unsigned char PROGMEM wifi_logo[] = {
	0xf0, 0x00, 0x1c, 0x00, 0x07, 0x00, 0xf3, 0x00, 0x1d, 0x80, 0xc4, 0x80, 0xf6, 0xc0, 0x12, 0x40, 
	0xda, 0x40, 0xda, 0x40
};

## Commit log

2022-10-03 Adding datasheets
    [SolderPasteStencil-gts-8576637044.stl]
2022-10-03 Add README
    [SolderPasteStencil-gts-8576637044.stl]
2022-10-03 Add schematic
2026-10-01 Add mDNS light discovery, versioning, and UX improvements
    Replace the two hardcoded light IPs with automatic discovery and a set
    of reliability/usability improvements, all verified on hardware.
    - mDNS discovery: find Elgato Key Lights via _elg._tcp instead of
    hardcoded IPs; multi-pass merge with queryHost fallback for the
    flaky first query; control all discovered lights (up to MAX_LIGHTS).
    - Self-healing: periodic re-discovery (30 min) and re-discovery when a
    known light stops answering, so a changed DHCP IP recovers without a
    reboot; fast 30s retry while no lights are known.
    - Disable WiFi modem power save, the root cause of intermittent mDNS
    (it was dropping multicast packets).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
    [main.cpp]
2026-10-09 Fix dropped button presses + add power-on splash
    v0.7.0 - never drop a button press during network blocking:
    - Sample buttons in a dedicated FreeRTOS task on core 0 that latches
    presses; loop() (core 1) drains them each pass. Presses are captured
    even while loop() is blocked for seconds in mDNS discovery or HTTP.
    Root cause was reproduced on hardware (15 taps -> only 10 registered
    when they landed during a ~14s discovery block).
    - Reduce discovery blocking: 2 query passes instead of 3, no back-to-back
    re-discovery within a poll, and back off the no-lights retry 30s -> 90s.
    - Bound HTTP with 2s connect/read timeouts and cap setLightState retries
    at one, so an unreachable light sta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
2026-10-20 Make control resilient to weak WiFi; fix 0% on, socket noise
    Diagnosed on hardware: at ~-73 dBm the controller dropped mDNS multicast
    (discovery found 0 lights) and HTTP responses took ~1.8s, which the 2s
    timeout from v0.7.0 cut off -> lights became uncontrollable.
    - Raise GET/PUT timeouts to 5s so slow responses on a weak link succeed.
    - Fall back to the known light IPs when mDNS discovery returns none, so
    control survives multicast/mDNS outages; mDNS still wins when it works.
    - Bump brightness to 10% when turning a light on from 0%, so "on" is visible.
    - Log WiFi RSSI with each poll for weak-signal diagnosis.
    - Drop a setNoDelay() call that ran before connect (logged a harmless
    Bad fi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

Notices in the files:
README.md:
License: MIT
